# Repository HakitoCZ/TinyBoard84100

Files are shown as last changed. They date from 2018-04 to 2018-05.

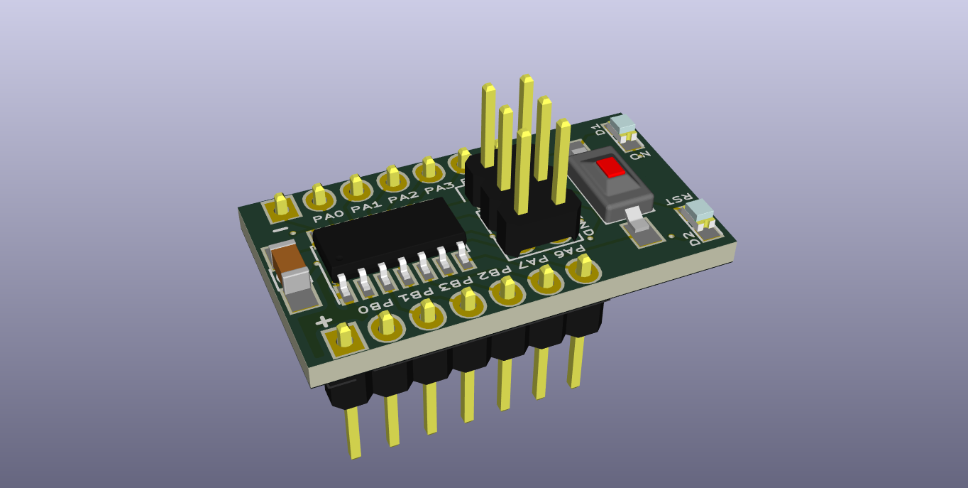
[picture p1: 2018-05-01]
TinyBoard84100-1.png

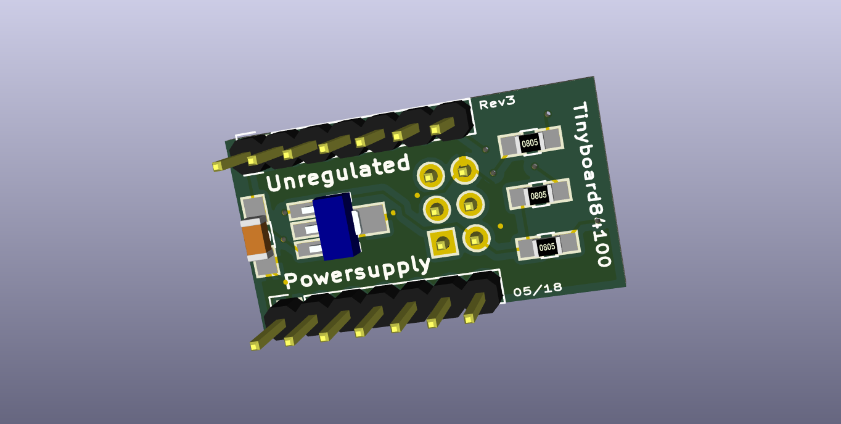
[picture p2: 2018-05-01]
TinyBoard84100-2.png

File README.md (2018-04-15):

# TinyBoard84100

Tiny beakout board for the ATtiny841 (or any other 14 pin
AVR) with AVR ISP programming header, voltage regulated and
with reset button.

It is programmable with the Arduino IDE with the ATtiny
library addon thingy. Or a proper toolchain for all the
tryhard nerds out there :)

Designed in KiCAD open-source and possibly for sale on Tindie
somewhere in the future. No promisses.

It's actually a second version of the design, first was not
published nor tested. It was designed, manufactured and forgoten about.

If you're experienced and want to tell me how wrong I did
everything, feel free to PM me. I'm open to your feedback.

Q: What's so special about the ATtiny841?

A: Compared to ATtiny84, the ATtiny841 has one extra 16-bit
timer with two PWM channels, one more
ADC, more input channels, one extra comparator, one extra USART.
And for more details go check Microchip's product site.
If you want to build it yourself, ATtiny84 seem to be pin compatible
so you should be just fine using that if you want to shave off
few cents and/or don't need the extra functionality of 841.

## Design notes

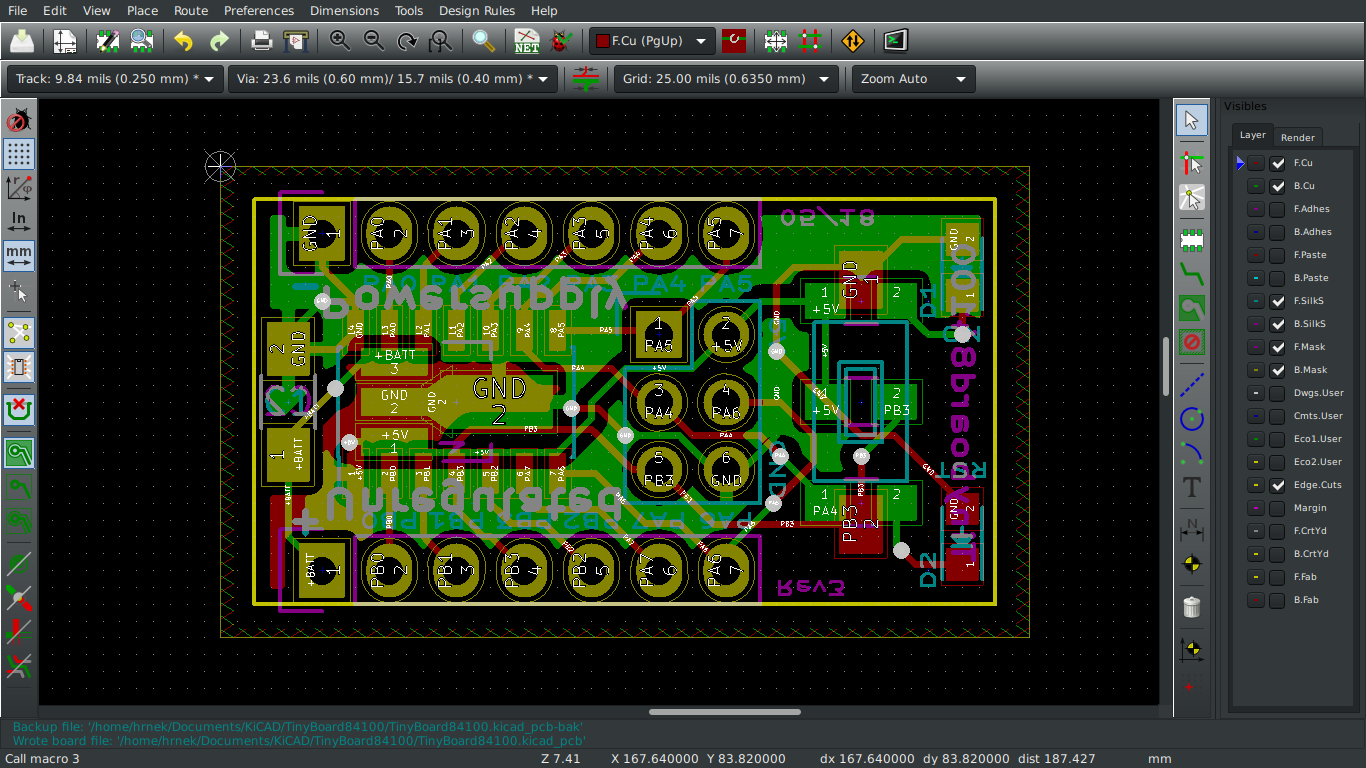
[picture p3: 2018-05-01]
TinyBoard84100-3.png

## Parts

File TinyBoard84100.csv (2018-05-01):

Id | Designator | Package | Quantity | Designation | Supplier and ref
1 | P4 | Pin_Header_Straight_2x03 | 1 | CONN_02X03
2 | C1 | C_1206_HandSoldering | 1 | 4.7uF
3 | C2 | C_1206_HandSoldering | 1 | 1uF
4 | D1,D2 | LED_0805 | 2 | LED
5 | P2,P3 | Pin_Header_Straight_1x07 | 2 | CONN_01X07
6 | R1,R2,R3 | R_0805_HandSoldering | 3 | 1k
7 | SW1 | SW_SPST_FSMSM | 1 | SW_PUSH
8 | U1 | SOT89-3_Housing_Handsoldering | 1 | 78L05
9 | U2 | SOIC-14_3.9x8.7mm_Pitch1.27mm | 1 | ATTINY841

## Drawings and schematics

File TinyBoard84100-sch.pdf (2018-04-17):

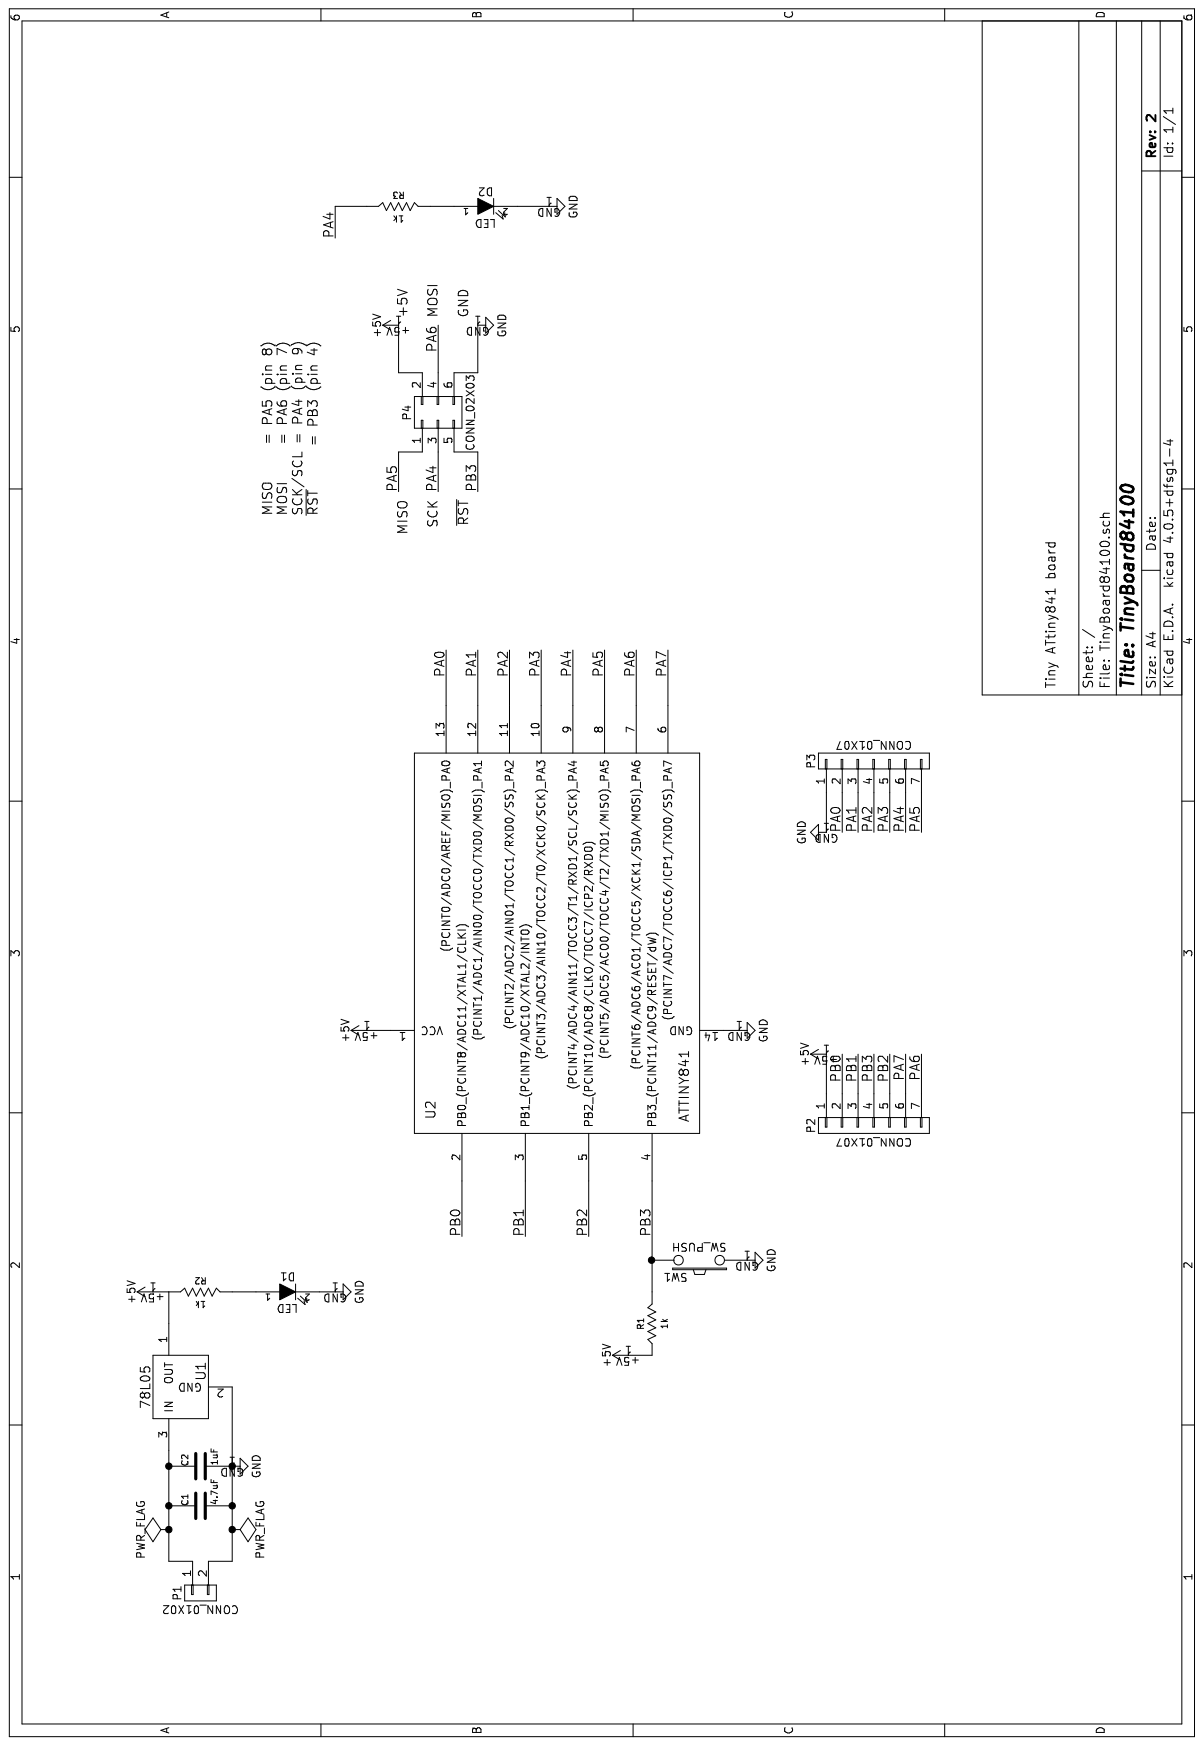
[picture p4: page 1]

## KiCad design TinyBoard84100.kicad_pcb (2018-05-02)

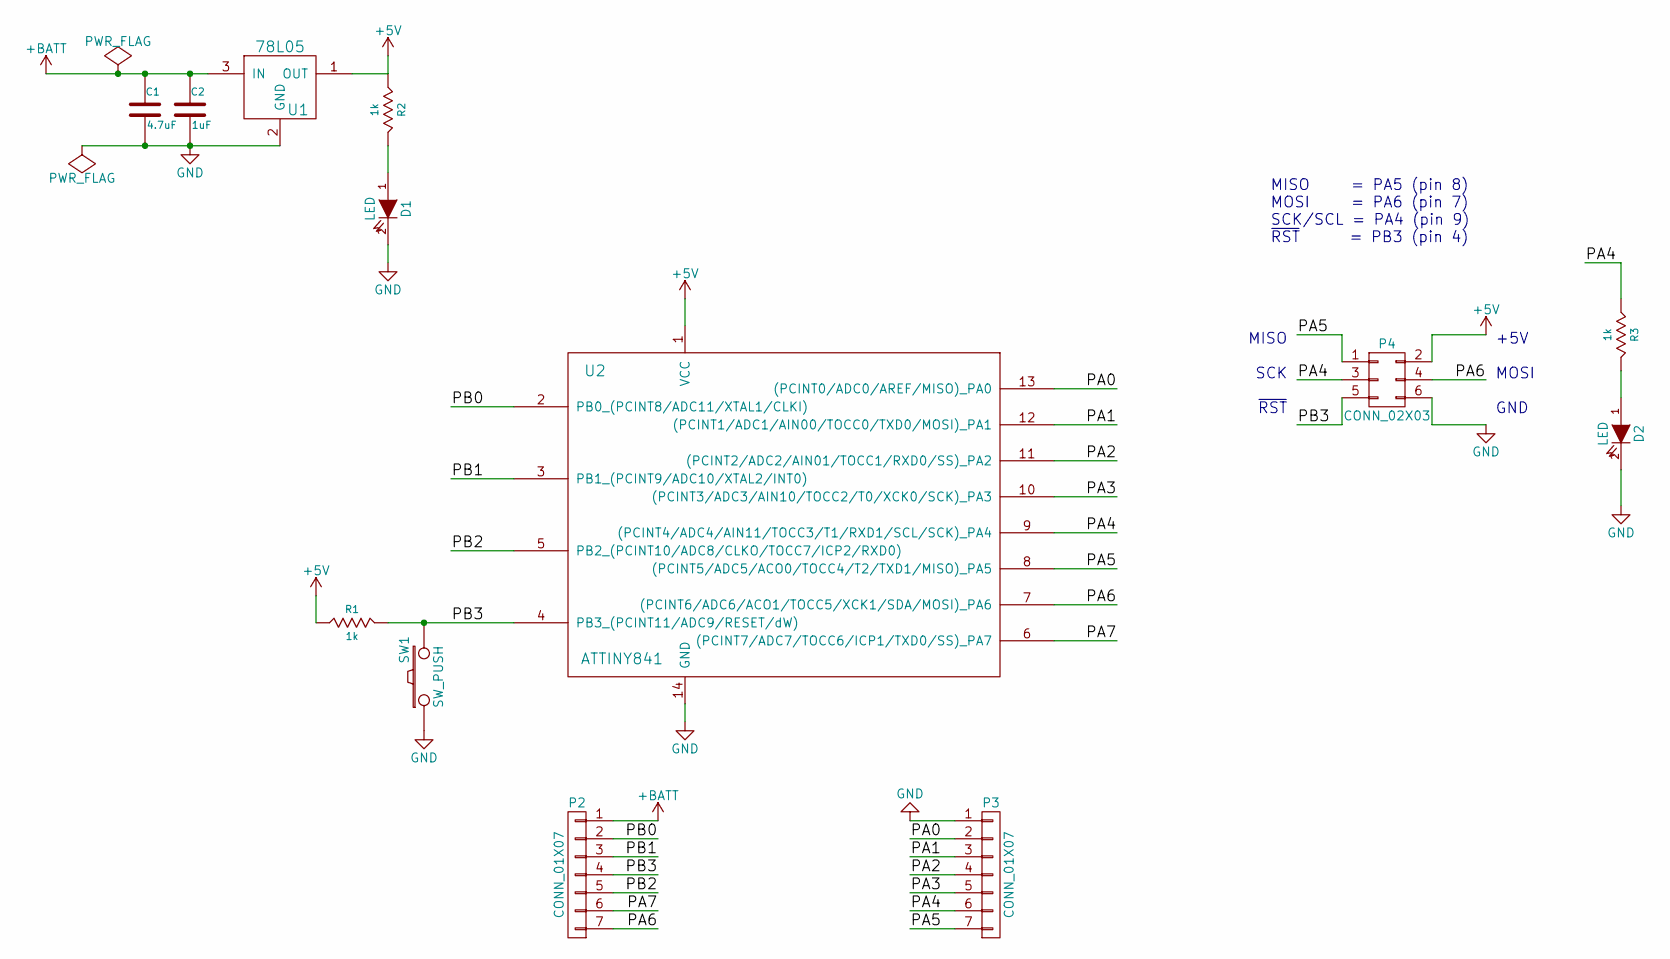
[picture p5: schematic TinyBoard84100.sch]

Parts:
C1: 4.7uF; C_1206_HandSoldering
C2: 1uF; C_1206_HandSoldering
D1, D2: LED; LED_0805
P2, P3: CONN_01X07; Pin_Header_Straight_1x07
P4: CONN_02X03; Pin_Header_Straight_2x03
R1, R2, R3: 1k; R_0805_HandSoldering
SW1: SW_PUSH; SW_SPST_FSMSM
U1: 78L05; SOT89-3_Housing_Handsoldering
U2: ATTINY841; SOIC-14_3.9x8.7mm_Pitch1.27mm

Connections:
+5V: P4.2, R1.1 (A), R2.1 (A), U1.1 (OUT), U2.1 (VCC)
+BATT: C1.1, C2.1, P2.1, U1.3 (IN)
/PA0: P3.2, U2.13 ((PCINT0/ADC0/AREF/MISO)_PA0)
/PA1: P3.3, U2.12 ((PCINT1/ADC1/AIN00/TOCC0/TXD0/MOSI)_PA1)
/PA2: P3.4, U2.11 ((PCINT2/ADC2/AIN01/TOCC1/RXD0/SS)_PA2)
/PA3: P3.5, U2.10 ((PCINT3/ADC3/AIN10/TOCC2/T0/XCK0/SCK)_P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)
/PA4: P3.6, P4.3, R3.1 (A), U2.9 ((PCINT4/ADC4/AIN11/TOCC3/T1/RXD1/SCL/SC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)
/PA5: P3.7, P4.1, U2.8 ((PCINT5/ADC5/ACO0/TOCC4/T2/TXD1/MISO)_P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)
/PA6: P2.7, P4.4, U2.7 ((PCINT6/ADC6/ACO1/TOCC5/XCK1/SDA/MOSI)_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)
/PA7: P2.6, U2.6 ((PCINT7/ADC7/TOCC6/ICP1/TXD0/SS)_PA7)
/PB0: P2.2, U2.2 (PB0_(PCINT8/ADC11/XTAL1/CLKI))
/PB1: P2.3, U2.3 (PB1_(PCINT9/ADC10/XTAL2/INT0))
/PB2: P2.5, U2.5 (PB2_(PCINT10/ADC8/CLKO/TOCC7/ICP2/RXD0))
/PB3: P2.4, P4.5, R1.2 (K), SW1.2, U2.4 (PB3_(PCINT11/ADC9/RESET/dW))
GND: C1.2, C2.2, D1.2 (K), D2.2 (K), P3.1, P4.6, SW1.1, U1.2 (GND), U2.14 (GND)
unnamed: D1.1 (A), R2.2 (K)
unnamed: D2.1 (A), R3.2 (K)

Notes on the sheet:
MISO SCK ~RST
+5V MOSI GND
MISO = PA5 (pin 8) MOSI = PA6 (pin 7) SCK/SCL = PA4 (pin 9) ~RST~ = PB3 (pin 4)

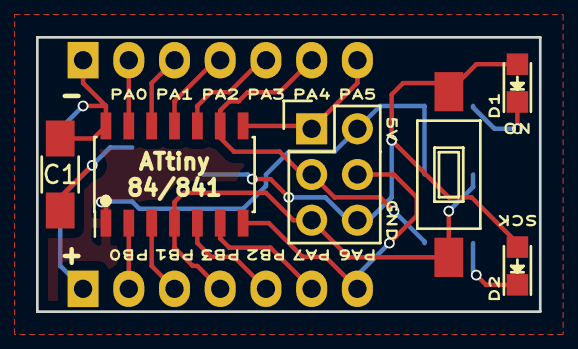
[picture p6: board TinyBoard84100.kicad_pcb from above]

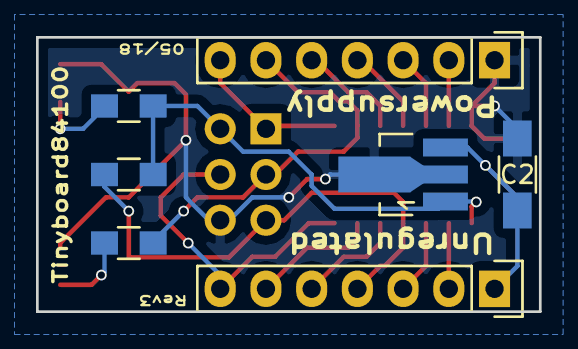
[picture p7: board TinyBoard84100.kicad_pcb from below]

Board: 2 copper layers, 27.9 x 15.2 mm, 13 parts (7 on the bottom side), 17 nets.

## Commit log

2018-04-15 Wiring ideas
    [TinyBoard84100.sch]
2018-04-15 Wires and lables
    [TinyBoard84100.sch]
2018-04-15 more wires and labels
    [TinyBoard84100.sch]
2018-04-15 finishing schematic
    [TinyBoard84100.sch]
2018-04-15 annotated & erc passed
    [TinyBoard84100.sch]
2018-04-15 generated netlist & bom
2018-04-15 footprints associated
    [TinyBoard84100.sch]
2018-04-15 new pcb with footprints
    [TinyBoard84100.kicad_pcb]
2018-04-15 First layout
    [TinyBoard84100.kicad_pcb]
2018-04-15 fixed zone connections
    [TinyBoard84100.kicad_pcb]
2018-04-17 silkscreen edits
    [TinyBoard84100.kicad_pcb]
2018-04-17 various exports
    [TinyBoard84100.kicad_pcb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]
2018-04-29 corrected footprints
    [TinyBoard84100.sch]
2018-04-29 update warning
    [TinyBoard84100.kicad_pcb]
2018-05-01 starting over
    [TinyBoard84100.kicad_pcb]
2018-05-01 first ideas
    [TinyBoard84100.kicad_pcb]
2018-05-01 almost finished layout
    [TinyBoard84100.kicad_pcb]
2018-05-01 layout finished
    [TinyBoard84100.kicad_pcb]
2018-05-01 updated gerbers
    [TinyBoard84100-B.Cu.gbr, TinyBoard84100-B.Mask.gbr, TinyBoard84100-B.SilkS.gbr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]
2018-05-02 finishing touches
    [TinyBoard84100.kicad_pcb]
